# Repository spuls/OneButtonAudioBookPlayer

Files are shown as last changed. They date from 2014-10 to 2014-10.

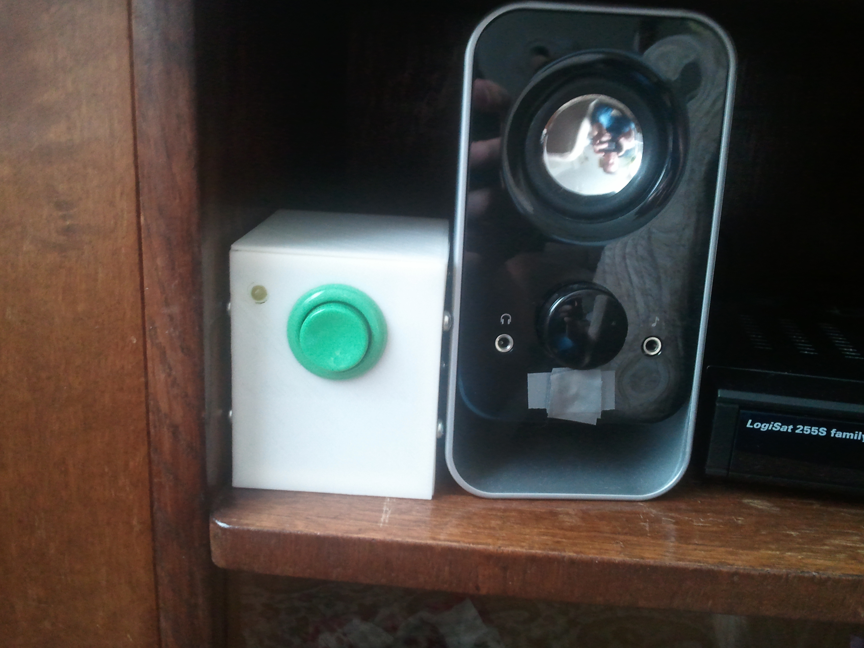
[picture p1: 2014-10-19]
Fotos/AssemblyWithSpeaker.jpg

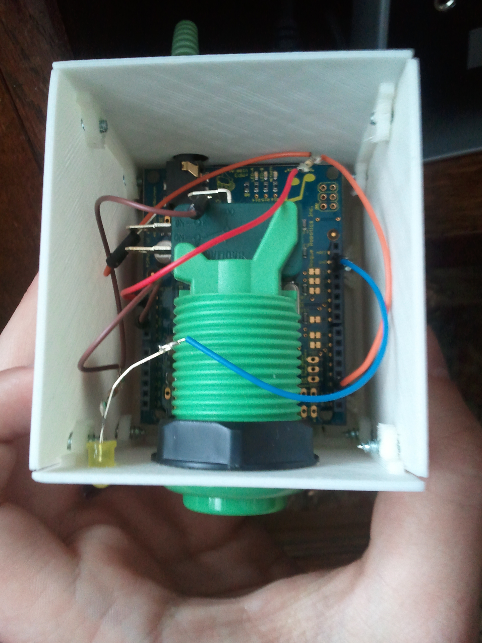
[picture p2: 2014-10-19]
Fotos/Internals.jpg

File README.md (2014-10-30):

OneButtonAudioBookPlayer
========================

Arduino based audio book player to be controlled with only one button - targeted user: elderly grandparent.

## Electronics
The Arduino is used to control a Rogue MP3 shield. That shield has SD-card support, audio out and comes with 
appropriate libraries to ease programming. The audio out is without amplifier, thus, a speaker system with 
amplifier is needed. When using headphones this needs to be considered if dealing with hearing impaired people.

## Usage of player:
- The user interface is a single button. The prototype uses a big green button to turn playback on and off. 
  The state of playback is visualized via a green LED.
- When resuming playback afer pausing the last 10 seconds are repeated. I find, this makes it easier to follow
  after a brake.
- When the end of the last file is reached, playback starts with first file again.

## Tips for filling the SD-card
- The order of files copied (not their actual alphabetical order) defines the order of playback (so far). 
  The SD-card library returns a list of found files in that order. No sorting was additionally implemented.
  (The same behaviour had my old iRiver mp3 player as well, so I was used to that.)
- This should obviously not be done by the targeted enduser (i.e. elderly grandparent).

## Tips for changing the SD-card
- When the card has to be changed, due to finished audio book, the player's power supply needs to be unplugged.
  After inserting the newly filled card the player can be plugged in again. During start-up the card is scanned,
  and determined if new content is on card - if so: start playback with first file, 
  else: continue playback from last known position.
- Again, this should obviously not be done by the targeted enduser (i.e. elderly grandparent).

## 3D printing stuff
- Each side of the assembly has to printed.
- The bottom and side parts are skrewed together. The top is "press"-fit - don't really press, be gentle.
- SketchUp files are included (formerly known as Google SketchUp). Version 8 was used.
- For simply printing stuff, the *.stl files are also included.

## History
The idea came to me in 2011. In the winter of 2012 I got to actually doing stuff. 
Since December 2012 the device is in use by my grand mother (aged 90). First she actually listened to audio books with it.
My parents put new books onto the SD card whenever needed. Nowadays she only listens to music with it. 
Audio book require quite a bit of mental concentration which is not achievable for her for longer periods any more.
There is enough music on the SD card to keep her happy for a long time. The repeating feature after the last file on card is reached helps in this case.

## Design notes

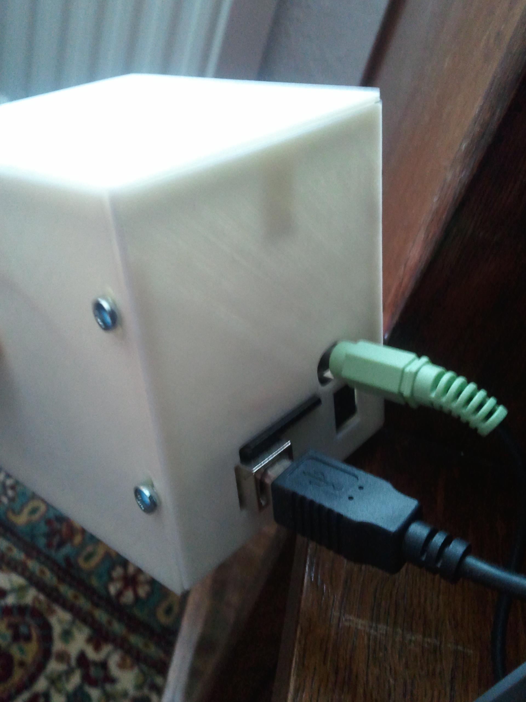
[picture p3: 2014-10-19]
Fotos/Backside.jpg

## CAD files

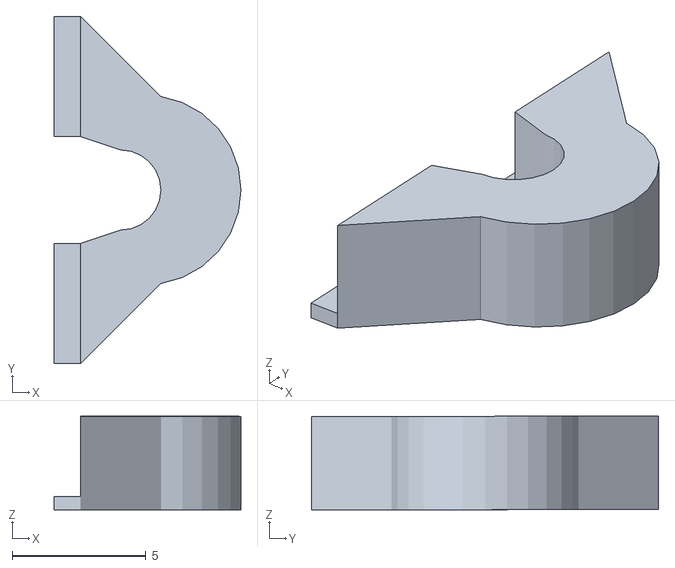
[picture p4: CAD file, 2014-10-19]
3DPrint/SkrewHole.stl
7.00 x 13.0 x 3.50

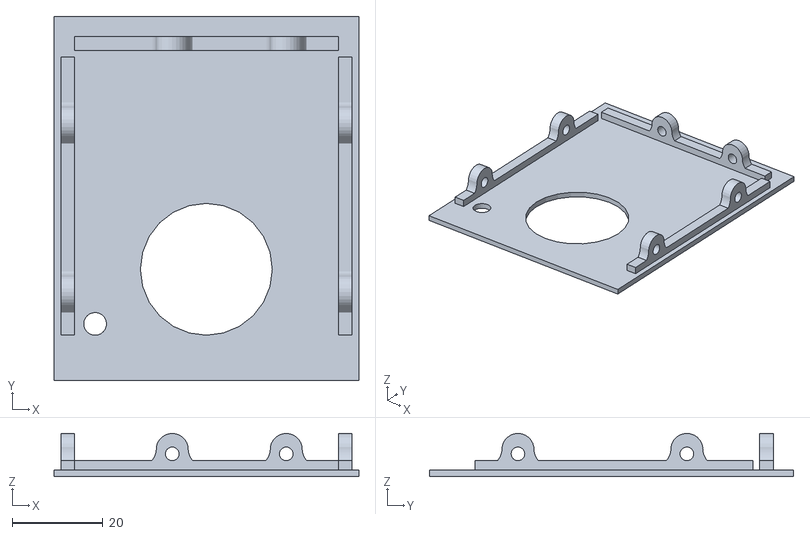
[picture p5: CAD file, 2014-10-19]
3DPrint/Front.stl
67.1 x 80.1 x 9.50

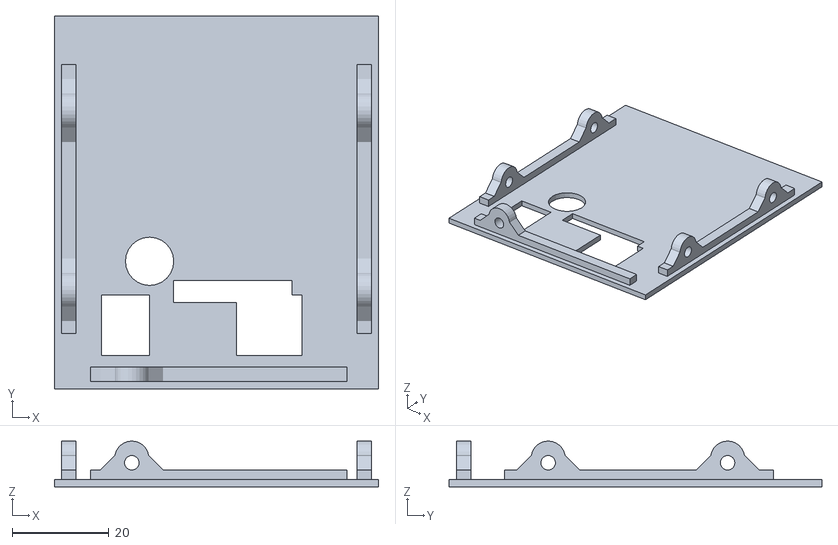
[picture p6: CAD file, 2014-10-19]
3DPrint/Back.stl
67.1 x 77.1 x 9.51

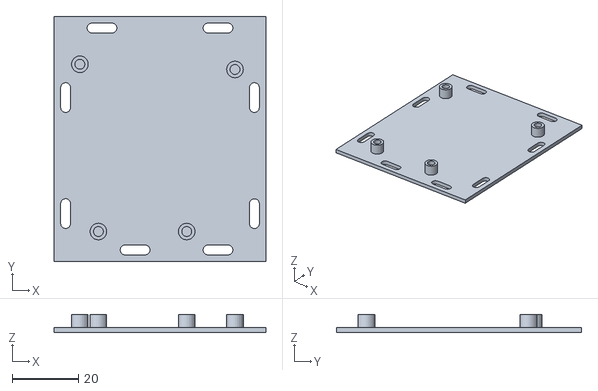
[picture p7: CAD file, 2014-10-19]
3DPrint/Base.stl
64.1 x 74.1 x 5.50

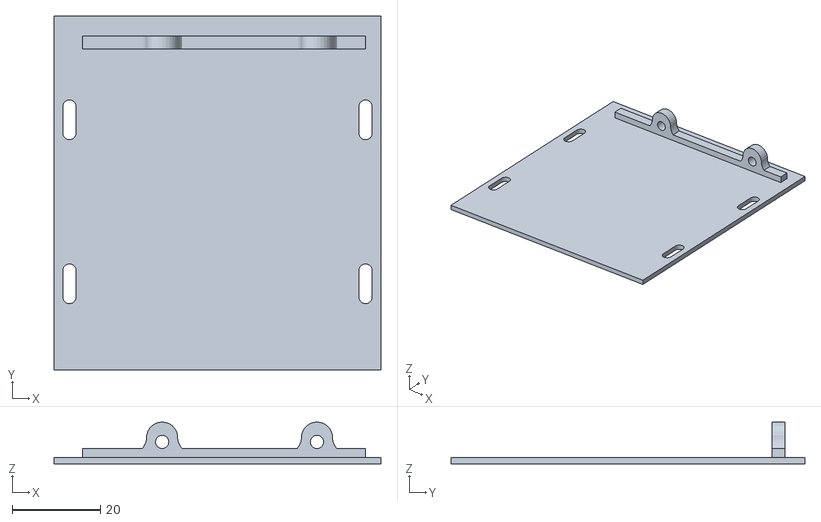
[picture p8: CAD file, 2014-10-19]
3DPrint/LeftSide.stl
74.1 x 80.1 x 9.50

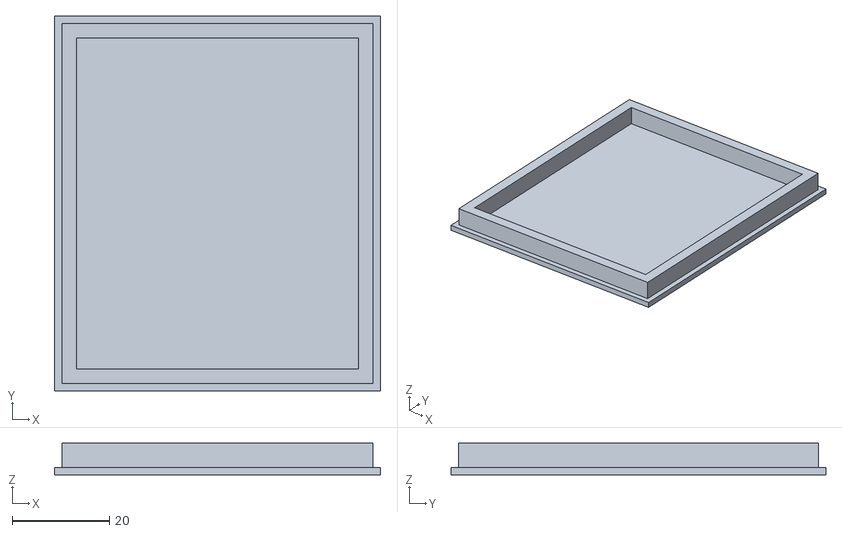
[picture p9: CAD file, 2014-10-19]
3DPrint/Top.stl
67.1 x 77.1 x 6.50

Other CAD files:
3DPrint/RightSide.stl
3DPrint/Back.skp
3DPrint/Base.skp
3DPrint/Components.skp
3DPrint/Front.skp
3DPrint/LeftSide.skp
3DPrint/RightSide.skp
3DPrint/SkrewHole.skp
3DPrint/Top.skp

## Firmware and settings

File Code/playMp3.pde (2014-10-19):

#include <NewSoftSerial.h>
#include <RogueMP3.h>
#include <RogueSD.h>

//#include <Serial.h>

// Definition of interrupt names
//#include < avr/io.h >
#include "C:\download\arduino\arduino-0023\hardware\tools\avr\avr\include\avr\io.h"
//#include <avr\include\avr\io.h>
// ISR interrupt service routine
//#include < avr/interrupt.h >
#include "C:\download\arduino\arduino-0023\hardware\tools\avr\avr\include\avr\interrupt.h"

NewSoftSerial rmp3_serial(6, 7);
RogueMP3 rmp3(rmp3_serial);
RogueSD filecommands(rmp3_serial);

// constants won't change. They're used here to 
// set pin numbers:
const int buttonPin = 2;     // the number of the pushbutton pin
const int ledPin =  13;      // the number of the LED pin


// variables will change:
volatile int buttonState = 0;         // variable for reading the pushbutton status
volatile int last_state = 0;
volatile int button_pressed = 0;

volatile int initStatus = 0; //0=uninit., 1=needReInit, 2=ReadFile, 3=SetParameter, 4=SaveFile, 5=Set up Player, 6=Initialized
boolean isPlaying = false;
volatile boolean doAction = false;

unsigned long button_time = 0;  
unsigned long last_button_time = 0;

// stat data
int32_t nrMP3s = 0;
uint32_t firstFileSize = 0;
uint16_t fileToPlay = 0;
uint16_t posInFile = 0;
int32_t nrMP3sRead = 0;
uint32_t fileSizeRead = 0;
uint16_t fileToPlayRead = 0;
uint16_t posInFileRead = 0;

char nameToPlay[128];

boolean noMoreFiles = false;


// Install the interrupt routine.
void pressedButton() 
{
   button_time = millis();
  //check to see if increment() was called in the last 250 milliseconds
  if (button_time - last_button_time < 750)
  {
    return;
  }
  last_button_time = button_time;
  // check the value again - since it takes some time to
  // activate the interrupt routine, we get a clear signal.
/*  buttonState = digitalRead(buttonPin);

  // check if the pushbutton is pressed.
  // if it is, the buttonState is HIGH:
  //if (buttonState == HIGH && last_state != buttonState) 
  if (buttonState == LOW && last_state != buttonState) 
  {     
    // turn LED on:    
    //digitalWrite(ledPin, HIGH);  
    button_pressed++;
    doAction = true;
    Serial.print("Do Action! ... ");
  }
  last_state = buttonState;
  */
  
  button_pressed++;
  doAction = true;
  return;
//  Serial.print("Do Action! ... ");
    
//  Serial.print("Pressed Button!\n");
}

void reInit()
{
  if(nrMP3s > 0)
  {
    char filename[128];
    filecommands.opendir("/");
    filecommands.readdir(filename, "*.mp3");
    int filehandle = filecommands.open(filename);
    fileinfo fi = filecommands.getfileinfo(filehandle);
    firstFileSize = fi.size;
    filecommands.close(filehandle);
    fileToPlay = 1;
    posInFile = 0;
  }
  else
  {
    firstFileSize = 0;
    fileToPlay = 0;
    posInFile = 0;
  }
  initStatus = 4;
}

//void saveInfo(int32_t *nr, uint32_t *fsize, uint16_t *fplay, uint16_t *pos)
void saveInfo()
{
  Serial.print("called saveInfo()\n");
  //noInterrupts();
//  Serial.print("some filecommands\n");
//  filecommands.closeall();
  filecommands.opendir("/");
  //  int fH = filecommands.getfreehandle();

//  Serial.print("open file\n");
  int fH = filecommands.open("playstat.txt", OPEN_RW);
/*
  if(fH==0)
  {
    Serial.print("No filehandles available!\n");
  }
  if(fH==-1)
  {
    Serial.print("Error requesting file handle!\n");
  }
  
  Serial.print("got handle\n");

  switch (filecommands.LastErrorCode)
  {
  case ERROR_INVALID_HANDLE:
    Serial.print("Invalid Handle\n");
    break;
  case ERROR_FILE_ALREADY_EXISTS:
    Serial.print("file already exists\n");
    break;
  case ERROR_OPEN_HANDLE_IN_USE:
    Serial.print("handle in use\n");
    break;
  case ERROR_OPEN_NO_FREE_HANDLES:
    Serial.print("no free handle\n");
    break;
  }
  */
  

 // int response = filecommands.writeln(fH, "");

//  Serial.print("write buffer\n");
  //  filecommands.open(fH, "playstat.txt", OPEN_WRITE);
  //  filecommands.writeln_prep(filehandle);
  char buff_save[128];
  sprintf(buff_save, "%li %lu %u %u", nrMP3s, firstFileSize, fileToPlay, posInFile);
  //  sprintf(buffer, "%d %d %d %d", *nr, *fsize, *fplay, *pos);
//  Serial.print("saveInfo: ");
//  Serial.print(buff_save);
  //filecommands.write(fH, strlen(buff_save), buff_save);
  
  
  filecommands.writeln_prep(fH);
  filecommands.print(buff_save);
  filecommands.writeln_finish();
  
  filecommands.close(fH);

//  Serial.print("\nsaveInfo finished\n");
  initStatus = 5;

  //interrupts();
}

void readFile()
{
  //Serial.print("Open playstat.txt\n");
  int filehandle = filecommands.open("playstat.txt", OPEN_RW);
  /*
  if(filehandle==0)
  {
    Serial.print("No filehandles available!\n");
  }
  if(filehandle==-1)
  {
    Serial.print("Error requesting file handle!\n");
  }
  
  Serial.print("got handle\n");

  switch (filecommands.LastErrorCode)
  {
  case ERROR_INVALID_HANDLE:
    Serial.print("Invalid Handle\n");
    break;
  case ERROR_FILE_ALREADY_EXISTS:
    Serial.print("file already exists\n");
    break;
  case ERROR_OPEN_HANDLE_IN_USE:
    Serial.print("handle in use\n");
    break;
  case ERROR_OPEN_NO_FREE_HANDLES:
    Serial.print("no free handle\n");
    break;
  }
  */
  char buffer[128];
  int ret = filecommands.read(filehandle, 128, buffer);
  filecommands.close(filehandle);

  
  if(ret>0)
  {
    //nrMP3sRead = atoi(buffer);
    sscanf(buffer, "%li %lu %u %u", &nrMP3sRead, &fileSizeRead, &fileToPlayRead, &posInFileRead);
  }
  initStatus = 3;
  /*
  Serial.print("nrMP3sRead, ret: ");
   Serial.print(ret); Serial.print(": "); Serial.print(nrMP3sRead); Serial.print(" ");
   Serial.print(fileSizeRead); Serial.print(" ");
   Serial.print(fileToPlayRead); Serial.print(" "); 
   Serial.print(posInFileRead); Serial.print(" "); Serial.print("\n");
   */
}

void setParameter()
{
  char filename[128];
  filecommands.opendir("/");
  filecommands.readdir(filename, "*.mp3");
  int fisrtfile = filecommands.open(filename);
  fileinfo fi = filecommands.getfileinfo(fisrtfile);
  uint32_t fileSize = fi.size;
  filecommands.close(fisrtfile);
  //check on actual data:
  if(nrMP3sRead != nrMP3s)
  {
    //Serial.print("nrMP3s: Need To ReInit!\n");
    //    reInit();
    initStatus = 1;
    return;
  }
  else if(fileSizeRead != fileSize)
  {
    /*
    Serial.print("fileSize: Need To ReInit!\n");
     Serial.print(fileSizeRead);
     Serial.print(" != ");
     Serial.print(fileSize);
     Serial.print("\n");
     */
    //    reInit();
    initStatus = 1;
    return;
  }
  else
  {
    firstFileSize = fileSize;
    fileToPlay = fileToPlayRead;
    posInFile = posInFileRead;
    initStatus = 5;

    Serial.print("set read values! ");
    Serial.print("posInFile: ");
    Serial.print(posInFile);
    Serial.print(", posInFileRead: ");
    Serial.print(posInFileRead);
    Serial.print("\n");

  }
}

void firstInit()
{
  /****************/
  /*
   * check if new audio book
   */
  /****************/
  // check on playstat.txt

    //Serial.print("find txt\n");
  filecommands.opendir("/");
  int32_t nrTXT = filecommands.filecount("*.txt");
  /*
  Serial.print("playstat.txt found: ");
   Serial.print(nrTXT);
   Serial.print("\n");
   */
  nrMP3s = filecommands.filecount("*.mp3");

  if(nrTXT == 0)
  {
    //no file found: need to read in new stat data
    initStatus = 1;
    //    reInit();
  }
  else
  {
    initStatus = 2;
    //stat file found: read data
    //Serial.print("Open playstat.txt\n");
    /*
    int filehandle = filecommands.open("playstat.txt", OPEN_RW);
     char buffer[16];
     int ret = filecommands.read(filehandle, 16, buffer);
     filecommands.close(filehandle);
     
     int32_t nrMP3sRead = 0;
     uint32_t fileSizeRead = 0;
     uint16_t fileToPlayRead = 0;
     uint16_t posInFileRead = 0;
     if(ret>0)
     {
     //nrMP3sRead = atoi(buffer);
     sscanf(buffer, "%li %lu %u %u", &nrMP3sRead, &fileSizeRead, &fileToPlayRead, &posInFileRead);
     }
     
     Serial.print("nrMP3sRead, ret: ");
     Serial.print(ret); Serial.print(": "); Serial.print(nrMP3sRead); Serial.print(" ");
     Serial.print(fileSizeRead); Serial.print(" ");
     Serial.print(fileToPlayRead); Serial.print(" "); 
     Serial.print(posInFileRead); Serial.print(" "); Serial.print("\n");
     
     char filename[128];
     filecommands.opendir("/");
     filecommands.readdir(filename, "*.mp3");
     int fisrtfile = filecommands.open(filename);
     fileinfo fi = filecommands.getfileinfo(fisrtfile);
     uint32_t fileSize = fi.size;
     filecommands.close(fisrtfile);
     //check on actual data:
     if(nrMP3sRead != nrMP3s)
     {
     //Serial.print("nrMP3s: Need To ReInit!\n");
     reInit();
     }
     else if(fileSizeRead != fileSize)
     {
     
     Serial.print("fileSize: Need To ReInit!\n");
     Serial.print(fileSizeRead);
     Serial.print(" != ");
     Serial.print(fileSize);
     Serial.print("\n");
     
     reInit();
     }
     else
     {
     firstFileSize = fileSize;
     fileToPlay = fileToPlayRead;
     posInFile = posInFileRead;
     
     Serial.print("set read values! ");
     Serial.print("posInFile: ");
     Serial.print(posInFile);
     Serial.print(", posInFileRead: ");
     Serial.print(posInFileRead);
     Serial.print("\n");
     
     }
     */
  }
  /*  
   Serial.print("Info found: nrMP3s: ");
   Serial.print(nrMP3s);
   Serial.print(", FileSize: ");
   Serial.print(firstFileSize);
   Serial.print(", fileToPlay: ");
   Serial.print(fileToPlay);
   Serial.print(", posInFile: ");
   Serial.print(posInFile);
   Serial.print("\n");
   */
  //  saveInfo();

}

/* @param file_nr starts at 0 */
boolean getFileName(uint16_t file_nr, char* name, int buffer_length)
{
  boolean ret = false;
  uint16_t counter = 0;
  char filename[buffer_length];
  filecommands.opendir("/");
  while(filecommands.readdir(filename, "*.mp3") == 0)
  {
    if(counter == file_nr)
    {
      strcpy(name, filename);
      ret = true;
      break;
    }
    counter++;
  }
//  Serial.println(name);
  return ret;
}

void setup()
{
  Serial.begin(9600);
  Serial.print("rmp3 init\n");
  rmp3_serial.begin(9600);

  Serial.print("rmp3 and file sync\n");
  rmp3.sync();
  filecommands.sync();
/*  
  char nTP[128];
  getFileName(1, nTP, 128); 
  nTP[127] = '\0';
*/
/*
  char nTP[128];
  filecommands.entrytofilename(nTP, 128, "./""*.mp3", 0);
  Serial.println(nTP);
  */
  
  

  Serial.print("set LEDs\n");  

  // initialize the LED pin as an output:
  pinMode(ledPin, OUTPUT);      
  // initialize the pushbutton pin as an input:
  pinMode(buttonPin, INPUT);

  //attachInterrupt(0, pressedButton, CHANGE);
  //attachInterrupt(0, pressedButton, FALLING);
  attachInterrupt(0, pressedButton, RISING);

  Serial.print("setup finished\n");
  /*
  char buffer[128];
   sprintf(buffer, "%li %lu %u %u", nrMP3s, firstFileSize, fileToPlay, posInFile);
   //sprintf(buffer, "%lu", firstFileSize);
   Serial.print("bevor saveInfo: ");
   Serial.print(buffer);
   */
  //saveInfo(&nrMP3s, &firstFileSize, &fileToPlay, &posInFile);

  /*
  char filename[128];
   filecommands.opendir("/");
   while(filecommands.readdir(filename, "*.mp3") == 0)
   {
   Serial.println(filename);
   }
   */


  //Serial.print("play file\n");
  //rmp3.playfile("01.mp3");
  //rmp3.playfile("/Daft Punk - Technologic.mp3");
  //Serial.print("done\n");
}

void loop()
{
//  Serial.print("loop\n");
  /*
  if(firstLoop)
   {
   firstLoop = false;
   //init player!
   firstInit();
   }
   */
  switch(initStatus)
  {
  case 0:
    {
      Serial.print("firstInit\n");
      firstInit();
      break;
    }
  case 1:
    {
      Serial.print("reInit\n");
      reInit();
      break;
    }
  case 2:
    {
      Serial.print("readFile\n");
      readFile();
      break;
    }
  case 3:
    {
      Serial.print("setParam\n");
      setParameter();
      Serial.print("setFileName\nfileToPlay: ");
      Serial.print(fileToPlay);
      Serial.print("\n");
//      filecommands.opendir("/");
      char nTP[128];
      //filecommands.entrytofilename(nTP, 128, "./""*.mp3", fileToPlay);
      getFileName(fileToPlay-1, nTP, 128);
      Serial.println(nTP);
      sprintf(nameToPlay, "%s", nTP);
      Serial.println(nameToPlay);
      Serial.print("\nsetFileName-Ende\n");
      break;
    }
  case 4:
    {
      Serial.print("saveInfo\n");
      saveInfo();
      break;
    }
  case 5:
    {
      Serial.print("play and pause.\n");
      //Serial.print(rmp3.getvolume());
      Serial.print("\n");
      rmp3.playfile(nameToPlay);
      int16_t leng = rmp3.gettracklength("/", nameToPlay);
      if(posInFile > leng)
      {
        Serial.print("Pos to long!\n");
      }
      else
      {
        rmp3.jump(posInFile);
      }
      rmp3.playpause();
      
      if(rmp3.getplaybackstatus() == 'P')
      {
        rmp3.playpause();
      }
      
      isPlaying = false;
      initStatus = 6;
      break;
    }
  case 6:
    {
      //Serial.print("Done\n");
      break;
    }
  }
  if(isPlaying && rmp3.getplaybackstatus() != 'P')
  {
    //should be playin' but isn't -> incremet file
//    Serial.print("increment file\n");
    posInFile = 0;
    fileToPlay++;
    /*
    if(nrMP3s < fileToPlay)
    {
      noMoreFiles = true;
      isPlaying = false;
    }
    else
    {
      char nTP[128];
//      filecommands.entrytofilename(nTP, 128, "./""*.mp3", fileToPlay);
      getFileName(fileToPlay-1, nTP, 128);
      sprintf(nameToPlay, "%s", nTP);
      rmp3.playfile(nameToPlay);
    }
    */
    if(nrMP3s < fileToPlay)
    {
      fileToPlay = 1;
      //noMoreFiles = true;
      //isPlaying = false;
    }
    
    char nTP[128];
//  filecommands.entrytofilename(nTP, 128, "./""*.mp3", fileToPlay);
    getFileName(fileToPlay-1, nTP, 128);
    sprintf(nameToPlay, "%s", nTP);
    rmp3.playfile(nameToPlay);
    
  }
  if(isPlaying && doAction)
  {
    //save and pause
    Serial.print("save and pause\n");
    doAction = false;
    playbackinfo info = rmp3.getplaybackinfo();
    posInFile = info.position;
    if(posInFile > 10)
    {
      posInFile -= 10;
    }
    else
    {
      posInFile = 0;
    }
    rmp3.playpause();
    isPlaying = false;
    saveInfo();
    Serial.print("return\n");
    return;
  }
  else if(!isPlaying && doAction && !noMoreFiles)
  {
    //load and play
    Serial.print("load and ... ");
    doAction = false;
    rmp3.playpause();
    isPlaying = true;
//    Serial.print("play\n");
  }
  if(button_pressed % 2 == 1)
  {
    digitalWrite(ledPin, HIGH);
//    isPlaying = true;

  }
  else
  {
    digitalWrite(ledPin, LOW);
//    isPlaying = false;
  }
}
